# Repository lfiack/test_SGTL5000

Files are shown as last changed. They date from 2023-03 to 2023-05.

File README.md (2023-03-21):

# Test SGTL5000
Test board for the SGTL5000 CODEC

## Notes
* SAI1_FS_A stands for frame synchronization, might be connected to CODEC's I2S_LRCLK pin (32/48/96kHz)
* SAI1_SD_A stands for serial data, connect to CODEC's I2S_DIN pin
* SAI1_SD_B is SAI B Synchronous Slave's serial data, connect to I2S_DOUT
* SAI1_SCK_A connect to I2S_SCLK (32/64 times FS frequency)
* SAI1_MCLK_A connecto to SYS_MCLK
    * "An integrated PLL is provided in the SGTL5000 that allows any clock from 8.0 to 27 MHz to be connected to SYS_MCLK"

* CODEC's CTRL_CLK is I2C SCL
* CODEC's CTRL_DATA is I2C SDA

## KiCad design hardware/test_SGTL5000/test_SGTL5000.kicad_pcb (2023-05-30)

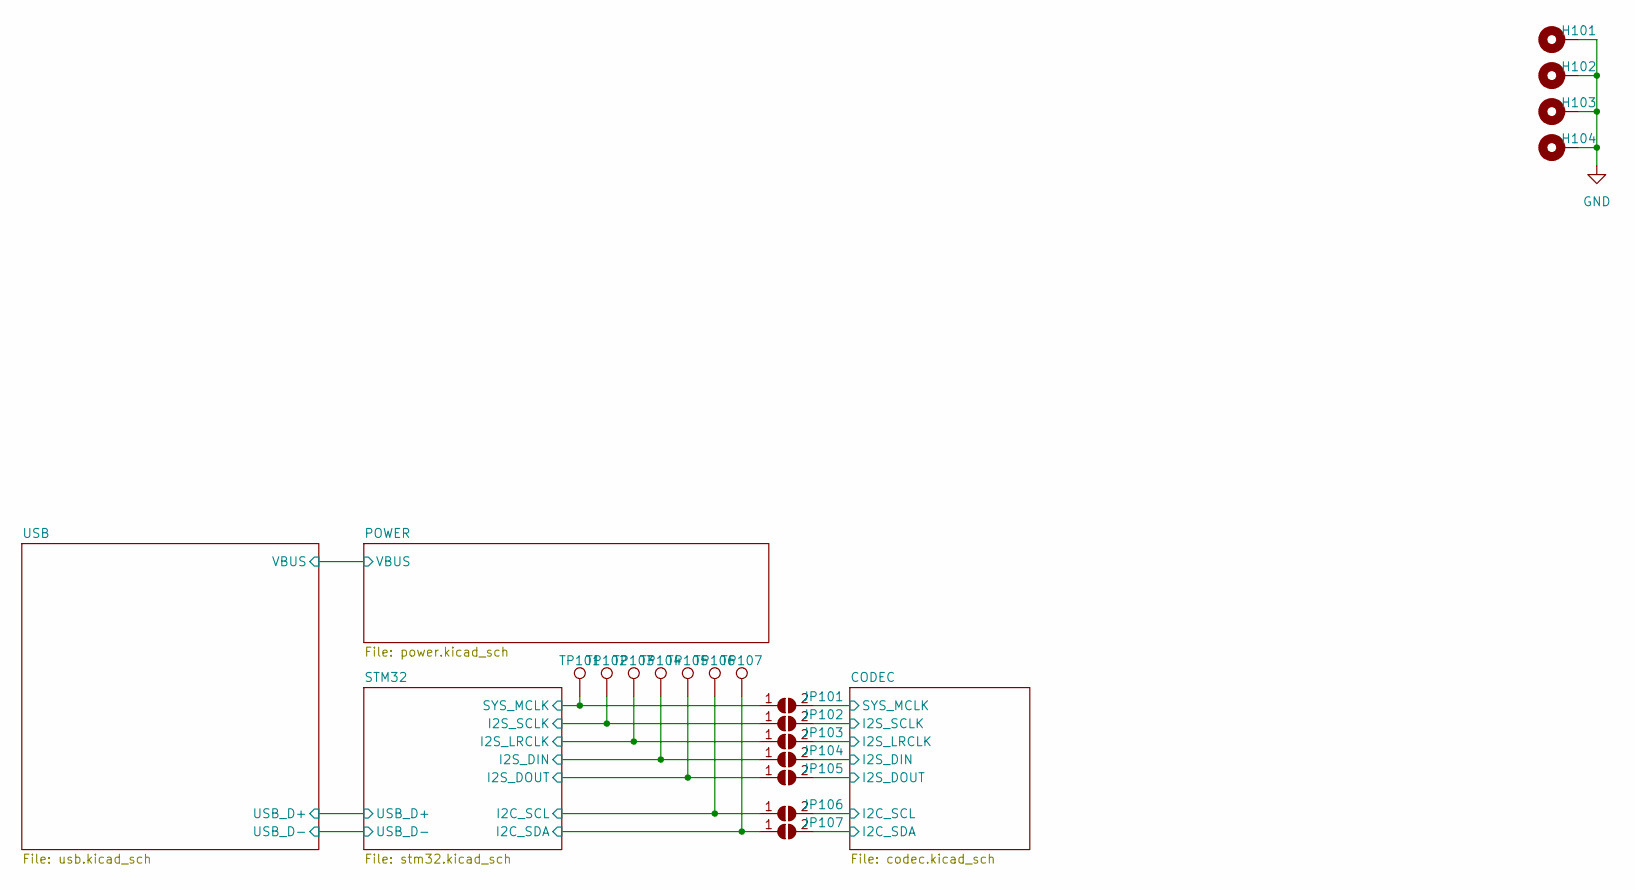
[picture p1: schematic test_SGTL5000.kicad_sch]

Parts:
H101, H102, H103, H104: MountingHole_Pad; MountingHole_3.2mm_M3_Pad_Via
JP101, JP102, JP103, JP104, JP105, JP106, JP107: SolderJumper_2_Open; R_0603_1608Metric
TP101, TP102, TP103, TP104, TP105, TP106, TP107: TestPoint; TestPoint_Pad_D1.5mm

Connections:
/CODEC/I2C_SCL: JP106.2 (B); also elsewhere on the board
/CODEC/I2C_SDA: JP107.2 (B); also elsewhere on the board
/CODEC/I2S_DIN: JP104.2 (B); also elsewhere on the board
/CODEC/I2S_DOUT: JP105.2 (B); also elsewhere on the board
/CODEC/I2S_LRCLK: JP103.2 (B); also elsewhere on the board
/CODEC/I2S_SCLK: JP102.2 (B); also elsewhere on the board
/CODEC/SYS_MCLK: JP101.2 (B); also elsewhere on the board
/STM32/I2C_SCL: JP106.1 (A), TP106.1; also elsewhere on the board
/STM32/I2C_SDA: JP107.1 (A), TP107.1; also elsewhere on the board
/STM32/I2S_DIN: JP104.1 (A), TP104.1; also elsewhere on the board
/STM32/I2S_DOUT: JP105.1 (A), TP105.1; also elsewhere on the board
/STM32/I2S_LRCLK: JP103.1 (A), TP103.1; also elsewhere on the board
/STM32/I2S_SCLK: JP102.1 (A), TP102.1; also elsewhere on the board
/STM32/SYS_MCLK: JP101.1 (A), TP101.1; also elsewhere on the board
GND: H101.1, H102.1, H103.1, H104.1; also elsewhere on the board

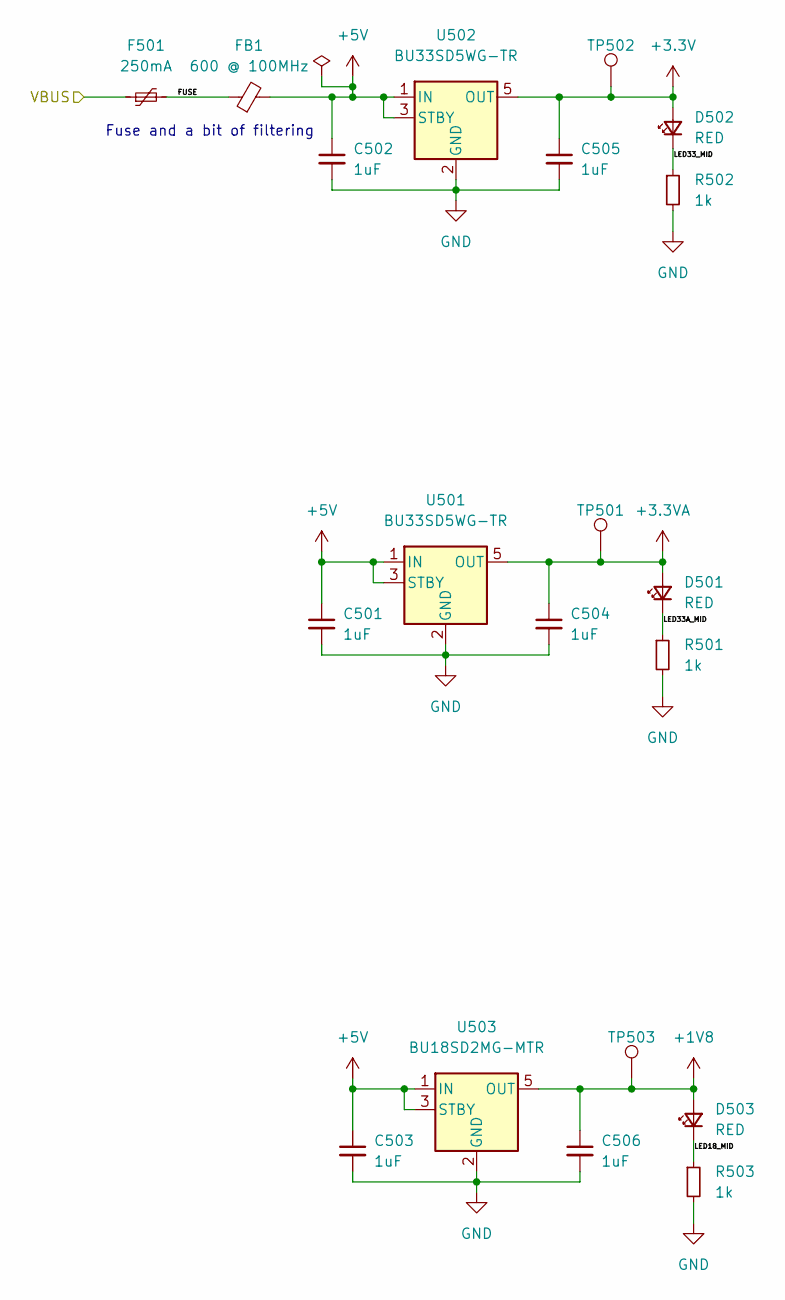
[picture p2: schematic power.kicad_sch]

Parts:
C501, C502, C503, C504, C505, C506: 1uF; C_0603_1608Metric
D501, D502, D503: RED; LED_0603_1608Metric
F501: 250mA; Fuse_1206_3216Metric; Farnell 2834880
FB1: 600 @ 100MHz; L_0805_2012Metric_Pad1.15x1.40mm_HandSolder; Farnell 2292460
R501, R502, R503: 1k; R_0603_1608Metric
TP501, TP502, TP503: TestPoint; TestPoint_Pad_D1.5mm
U501, U502: BU33SD5WG-TR; SOT-23-5
U503: BU18SD2MG-MTR; SOT-23-5

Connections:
+1V8: C506.1, D503.2 (A), TP503.1, U503.5 (OUT); also elsewhere on the board
+3.3VA: C504.1, D501.2 (A), TP501.1, U501.5 (OUT); also elsewhere on the board
+3V3: C505.1, D502.2 (A), TP502.1, U502.5 (OUT); also elsewhere on the board
+5V: C501.1, C502.1, C503.1, FB1.2, U501.1 (IN), U501.3 (STBY), U502.1 (IN), U502.3 (STBY), U503.1 (IN), U503.3 (STBY)
/POWER/FUSE: F501.2, FB1.1
/POWER/LED18_MID: D503.1 (K), R503.1
/POWER/LED33A_MID: D501.1 (K), R501.1
/POWER/LED33_MID: D502.1 (K), R502.1
/POWER/VBUS: F501.1; also elsewhere on the board
GND: C501.2, C502.2, C503.2, C504.2, C505.2, C506.2, R501.2, R502.2, R503.2, U501.2 (GND), U502.2 (GND), U503.2 (GND); also elsewhere on the board

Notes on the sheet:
Fuse and a bit of filtering

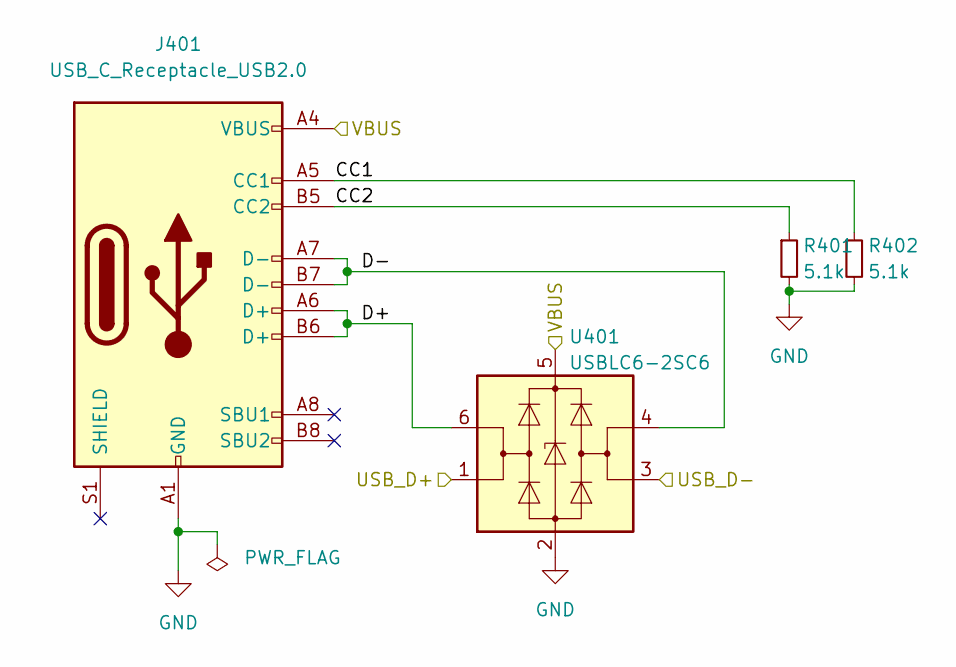
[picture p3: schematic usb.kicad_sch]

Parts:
J401: USB_C_Receptacle_USB2.0; USB_C_Receptacle_HRO_TYPE-C-31-M-12
R401, R402: 5.1k; R_0603_1608Metric
U401: USBLC6-2SC6; SOT-23-6

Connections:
/POWER/VBUS: J401.A4 (VBUS), J401.A9 (VBUS), J401.B4 (VBUS), J401.B9 (VBUS), U401.5 (VBUS); also elsewhere on the board
/STM32/USB_D+: U401.1 (I/O1); also elsewhere on the board
/STM32/USB_D-: U401.3 (I/O2); also elsewhere on the board
/USB/CC1: J401.A5 (CC1), R402.1
/USB/CC2: J401.B5 (CC2), R401.1
/USB/D+: J401.A6 (D+), J401.B6 (D+), U401.6 (I/O1)
/USB/D-: J401.A7 (D-), J401.B7 (D-), U401.4 (I/O2)
GND: J401.A1 (GND), J401.A12 (GND), J401.B1 (GND), J401.B12 (GND), R401.2, R402.2, U401.2 (GND); also elsewhere on the board

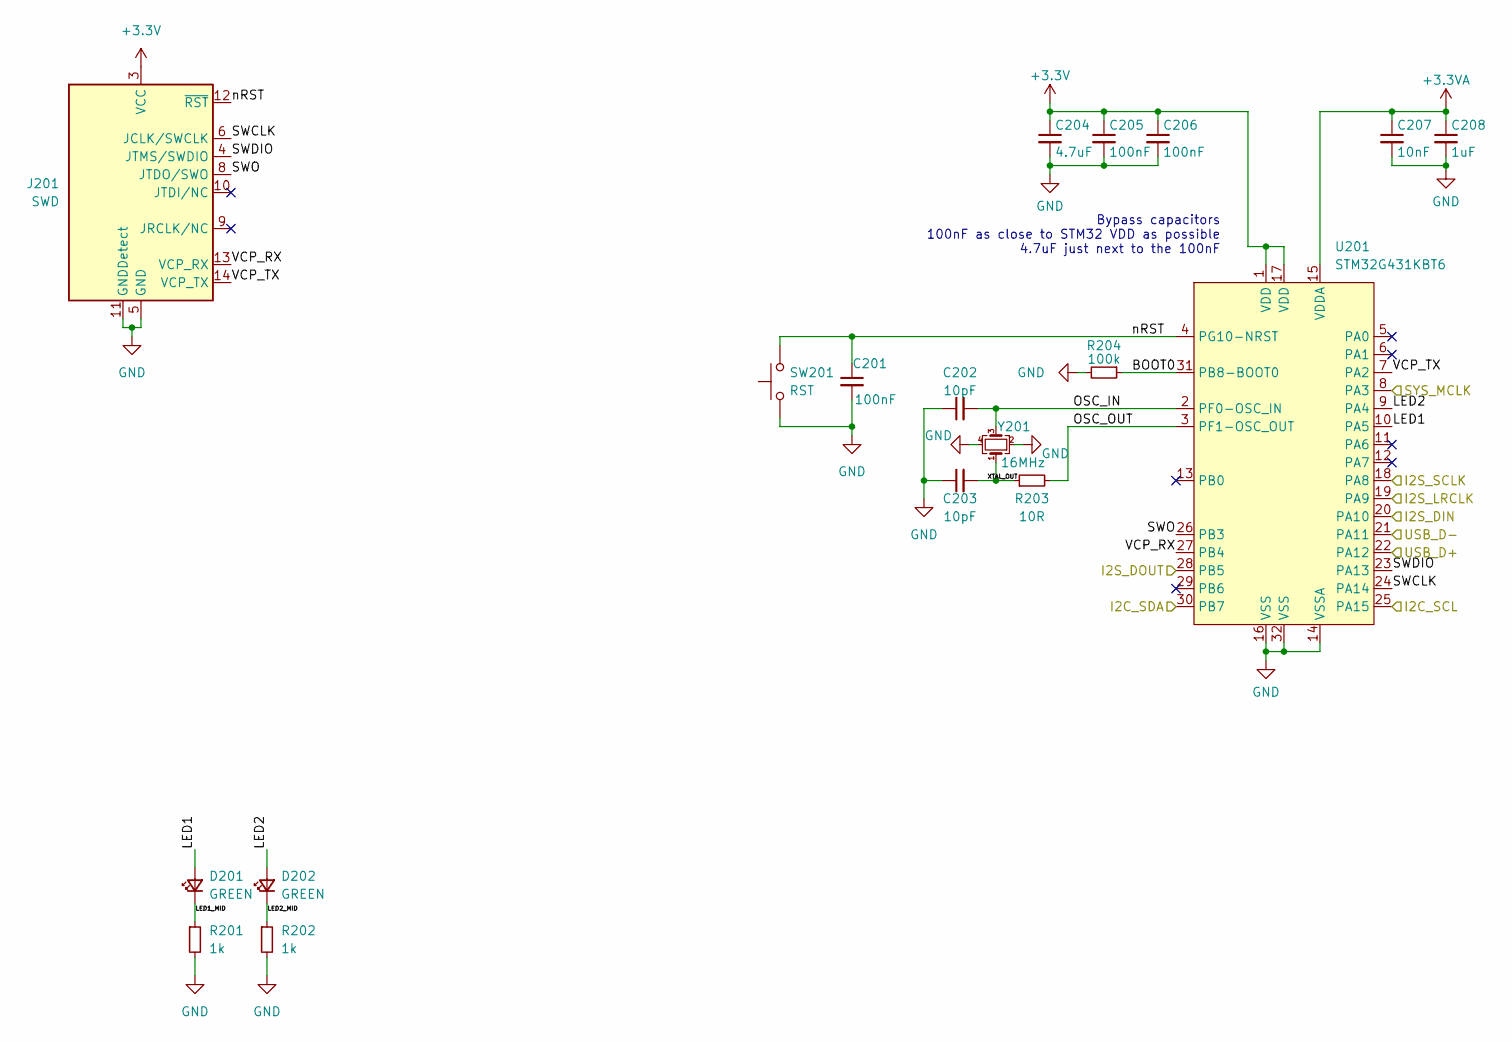
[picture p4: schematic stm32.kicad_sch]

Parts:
C201, C205, C206: 100nF; C_0402_1005Metric
C202, C203: 10pF; C_0402_1005Metric
C204: 4.7uF; C_0603_1608Metric; Farnell 3013398
C207: 10nF; C_0402_1005Metric
C208: 1uF; C_0603_1608Metric; Farnell 3013398
D201, D202: GREEN; LED_0603_1608Metric
J201: SWD; PinHeader_2x07_P1.27mm_Vertical_SMD
R201, R202: 1k; R_0603_1608Metric
R203: 10R; R_0603_1608Metric
R204: 100k; R_0402_1005Metric
SW201: RST; SW_SPST_B3U-1000P; Farnell 1333652
U201: STM32G431KBT6; LQFP-32_7x7mm_P0.8mm
Y201: 16MHz; Crystal_SMD_EuroQuartz_MT-4Pin_3.2x2.5mm; Farnell 2853935

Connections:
+3.3VA: C207.1, C208.1, U201.15 (VDDA); also elsewhere on the board
+3V3: C204.1, C205.1, C206.1, J201.3 (VCC), U201.1 (VDD), U201.17 (VDD); also elsewhere on the board
/STM32/BOOT0: R204.1, U201.31 (PB8-BOOT0)
/STM32/I2C_SCL: U201.25 (PA15); also elsewhere on the board
/STM32/I2C_SDA: U201.30 (PB7); also elsewhere on the board
/STM32/I2S_DIN: U201.20 (PA10); also elsewhere on the board
/STM32/I2S_DOUT: U201.28 (PB5); also elsewhere on the board
/STM32/I2S_LRCLK: U201.19 (PA9); also elsewhere on the board
/STM32/I2S_SCLK: U201.18 (PA8); also elsewhere on the board
/STM32/LED1: D201.2 (A), U201.10 (PA5)
/STM32/LED1_MID: D201.1 (K), R201.1
/STM32/LED2: D202.2 (A), U201.9 (PA4)
/STM32/LED2_MID: D202.1 (K), R202.1
/STM32/OSC_IN: C202.2, U201.2 (PF0-OSC_IN), Y201.3
/STM32/OSC_OUT: R203.2, U201.3 (PF1-OSC_OUT)
/STM32/SWCLK: J201.6 (JCLK/SWCLK), U201.24 (PA14)
/STM32/SWDIO: J201.4 (JTMS/SWDIO), U201.23 (PA13)
/STM32/SWO: J201.8 (JTDO/SWO), U201.26 (PB3)
/STM32/SYS_MCLK: U201.8 (PA3); also elsewhere on the board
/STM32/USB_D+: U201.22 (PA12); also elsewhere on the board
/STM32/USB_D-: U201.21 (PA11); also elsewhere on the board
/STM32/VCP_RX: J201.13 (VCP_RX), U201.27 (PB4)
/STM32/VCP_TX: J201.14 (VCP_TX), U201.7 (PA2)
/STM32/XTAL_OUT: C203.2, R203.1, Y201.1
/STM32/nRST: C201.1, J201.12 (~RST), SW201.2, U201.4 (PG10-NRST)
GND: C201.2, C202.1, C203.1, C204.2, C205.2, C206.2, C207.2, C208.2, J201.5 (GND), J201.7 (GND), J201.11 (GNDDetect), R201.2, R202.2, R204.2, SW201.1, U201.14 (VSSA), U201.16 (VSS), U201.32 (VSS), Y201.2, Y201.4; also elsewhere on the board

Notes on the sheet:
Bypass capacitors 100nF as close to STM32 VDD as possible 4.7uF just next to the 100nF

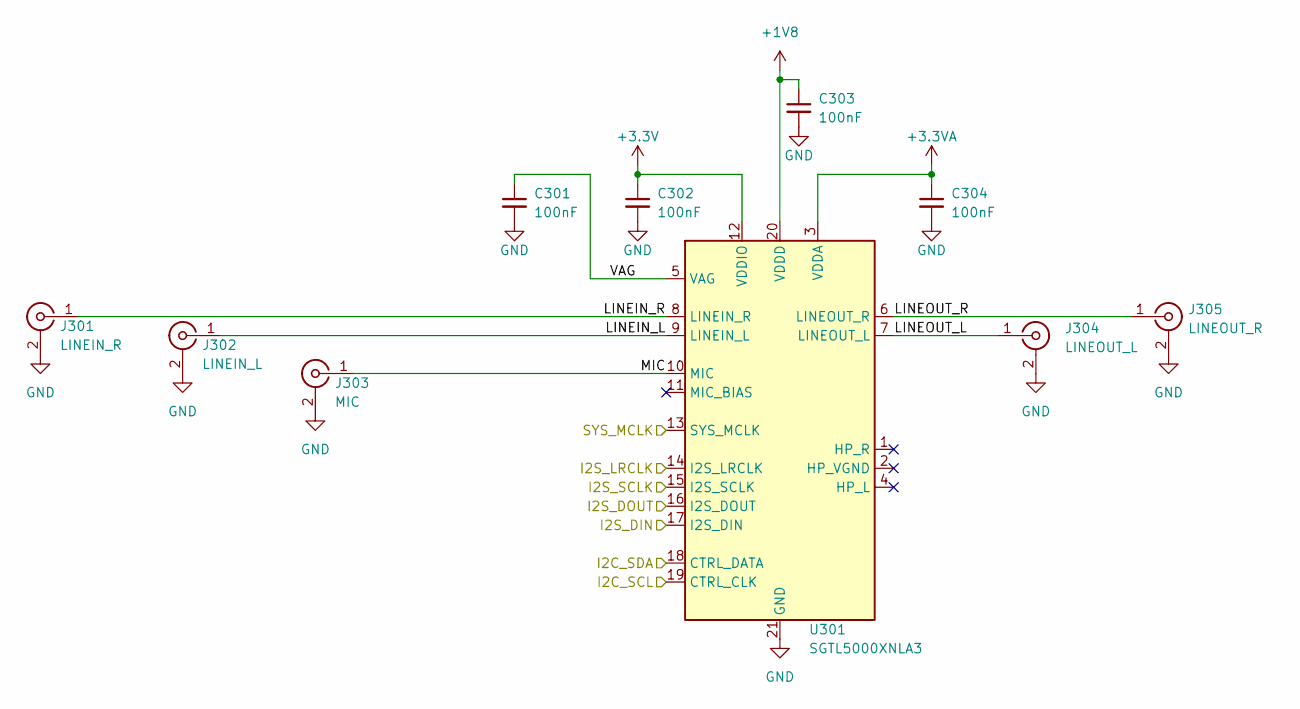
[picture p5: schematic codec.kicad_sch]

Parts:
C301, C302, C303, C304: 100nF; C_0402_1005Metric
J301: LINEIN_R; BNC_RS-PRO_546-4027
J302: LINEIN_L; BNC_RS-PRO_546-4027
J303: MIC; BNC_RS-PRO_546-4027
J304: LINEOUT_L; BNC_RS-PRO_546-4027
J305: LINEOUT_R; BNC_RS-PRO_546-4027
U301: SGTL5000XNLA3; QFN-20-1EP_3x3mm_P0.4mm_EP1.65x1.65mm

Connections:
+1V8: C303.1, U301.20 (VDDD); also elsewhere on the board
+3.3VA: C304.1, U301.3 (VDDA); also elsewhere on the board
+3V3: C302.1, U301.12 (VDDIO); also elsewhere on the board
/CODEC/I2C_SCL: U301.19 (CTRL_CLK); also elsewhere on the board
/CODEC/I2C_SDA: U301.18 (CTRL_DATA); also elsewhere on the board
/CODEC/I2S_DIN: U301.17 (I2S_DIN); also elsewhere on the board
/CODEC/I2S_DOUT: U301.16 (I2S_DOUT); also elsewhere on the board
/CODEC/I2S_LRCLK: U301.14 (I2S_LRCLK); also elsewhere on the board
/CODEC/I2S_SCLK: U301.15 (I2S_SCLK); also elsewhere on the board
/CODEC/LINEIN_L: J302.1 (In), U301.9 (LINEIN_L)
/CODEC/LINEIN_R: J301.1 (In), U301.8 (LINEIN_R)
/CODEC/LINEOUT_L: J304.1 (In), U301.7 (LINEOUT_L)
/CODEC/LINEOUT_R: J305.1 (In), U301.6 (LINEOUT_R)
/CODEC/MIC: J303.1 (In), U301.10 (MIC)
/CODEC/SYS_MCLK: U301.13 (SYS_MCLK); also elsewhere on the board
/CODEC/VAG: C301.1, U301.5 (VAG)
GND: C301.2, C302.2, C303.2, C304.2, J301.2 (Ext), J302.2 (Ext), J303.2 (Ext), J304.2 (Ext), J305.2 (Ext), U301.21 (GND); also elsewhere on the board

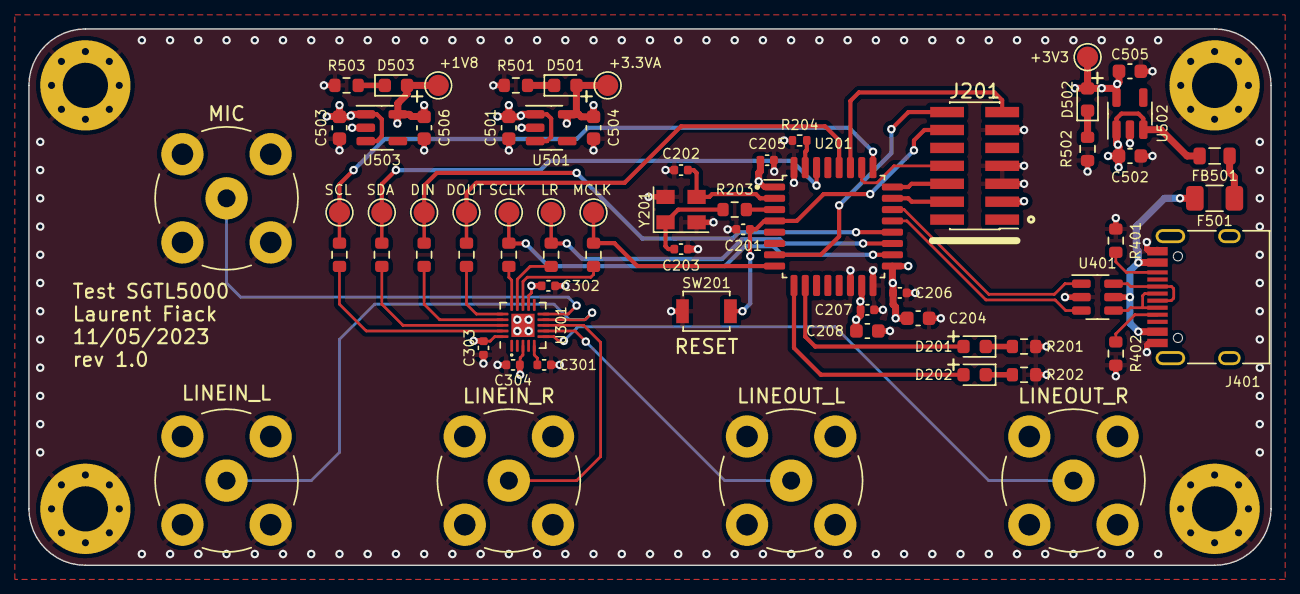
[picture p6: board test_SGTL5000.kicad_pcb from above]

Board: 4 copper layers, 88.0 x 38.0 mm, 70 parts (0 on the bottom side), 50 nets.

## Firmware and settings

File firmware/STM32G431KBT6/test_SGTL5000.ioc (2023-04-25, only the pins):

Mcu.UserName=STM32G431KBTx
PA10.Signal=SAI1_SD_A
PA11.Signal=USB_DM
PA12.Signal=USB_DP
PA13.Signal=SYS_JTMS-SWDIO
PA14.Signal=SYS_JTCK-SWCLK
PA15.Signal=I2C1_SCL
PA2.Signal=USART2_TX
PA3.Signal=SAI1_MCLK_A
PA4.GPIO_Label=LED2
PA4.Signal=GPIO_Output
PA5.GPIO_Label=LED1
PA5.Signal=GPIO_Output
PA8.Signal=SAI1_SCK_A
PA9.Signal=SAI1_FS_A
PB3.Signal=SYS_JTDO-SWO
PB4.Signal=USART2_RX
PB5.Signal=SAI1_SD_B
PB7.Signal=I2C1_SDA
PF0-OSC_IN.Signal=RCC_OSC_IN
PF1-OSC_OUT.Signal=RCC_OSC_OUT

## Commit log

2023-03-23 kicad project
    [codec.kicad_sch, power.kicad_sch, stm32.kicad_sch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]
2023-04-20 Started routing
    [stm32.kicad_sch, test_SGTL5000.kicad_pcb]
2023-05-11 finished routing
    [test_SGTL5000.kicad_pcb]
2023-05-11 small mod
    [test_SGTL5000.kicad_pcb]
2023-05-30 fabrication files
    [test_SGTL5000-B_Cu.gbr, test_SGTL5000-B_Mask.gbr, test_SGTL5000-Edge_Cuts.gbr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]
